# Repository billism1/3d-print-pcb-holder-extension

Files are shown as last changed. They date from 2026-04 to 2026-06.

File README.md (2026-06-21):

# PCB Holder Extension

Two OpenSCAD-designed solutions for mounting wider/longer PCBs that exceed a standard PCB holder's capacity: a cap-on extension and a full arm replacement.

> **📥 Download & print on MakerWorld:** [PCB Holder Arm Extension & Replacement](https://makerworld.com/en/models/2961782-pcb-holder-arm-extension-replacement)

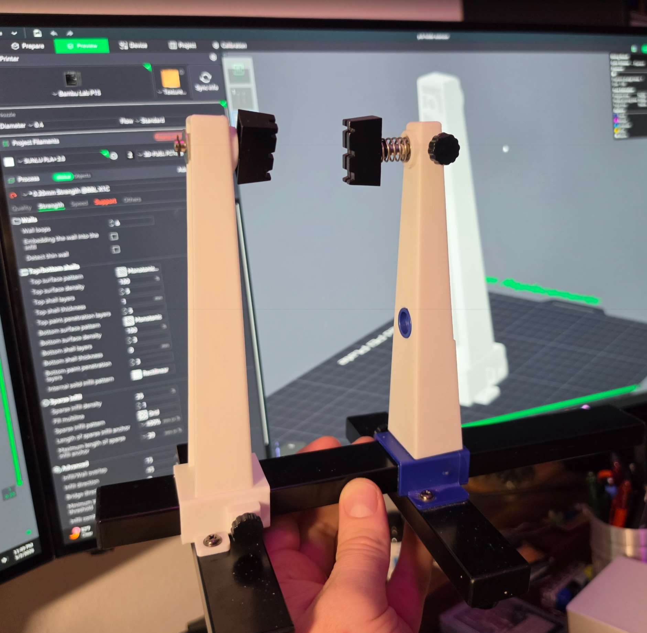
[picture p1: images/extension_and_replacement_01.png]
Extension (right) and full replacement arm (left) on shared base rail


## Target Holders

This extension is designed for standard PCB holders with ~200×140mm max capacity:

| Brand | Model | Max PCB Size | Link |
|---|---|---|---|
| Noah | NH-11E | 200×140mm | [Amazon](https://www.amazon.com/Noah-Adjustable-Soldering-Desoldering-Rotation/dp/B0CY4DRHWK/) |
| Pro's Kit | SN-390 | 200×140mm | [Adafruit](https://www.adafruit.com/product/3791) |

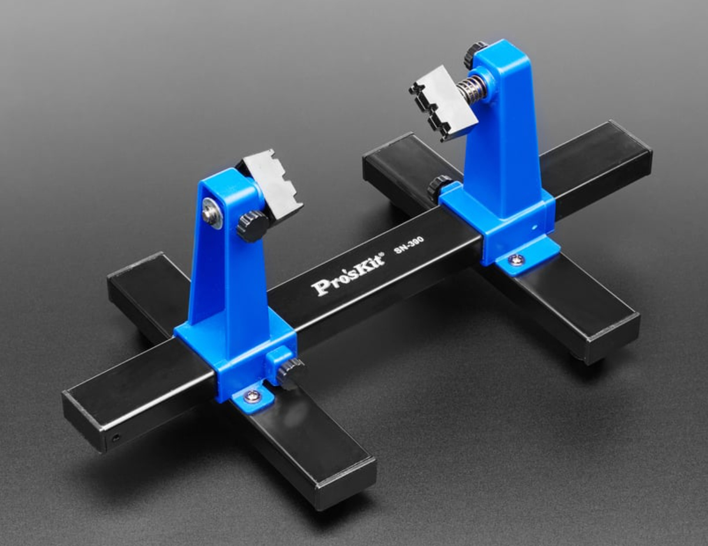
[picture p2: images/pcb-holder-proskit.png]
PCB Holder


### Pro's Kit SN-390 Specifications
- **Material**: ABS arms + metal base
- **Dimensions**: 300 × 165 × 125mm
- **Weight**: 450g
- **Features**: 4 slots for varying PCB thicknesses, non-slip rubber pads, 360° rotation

## Why

Standard PCB holders adjust horizontally and rotate PCBs in spring-loaded braces. Oversized PCBs can't rotate, though — they hit the holder frame. These parts add arm height so larger boards clear it.

Two approaches; choose one:

- **`pcb-holder-extension:`** Caps onto the top of each existing vertical arm, adding height above the original. One piece per side.
- **`pcb-holder-long-arm:`** Full replacement for the vertical arm. Taller profile, no base modification.

Either way, reuse the original holder's hardware.

## Hardware Assembly (Applies to Both Methods)

Both the extension and long arm replacement reuse the original holder's hardware. Follow these steps for either mounting method:

1. Slide the PCB grip bolt (reused from the original holder) through the bolt hole from inside to outside.
2. Place the washer (from the original holder) onto the bolt on the outside.
3. Press the retainer clip (from the original holder) onto the washer to lock it in place. The washer keeps the PCB grip bolt from sliding out, while the grip on the inner side prevents it from going anywhere.

### Mounting Method: Extension

Mounts on **both sides** of the holder (one piece per arm):

1. Slide the extension cap over the top of the existing vertical arm.
2. Follow the hardware assembly steps above.

### Mounting Method: Long Arm (Replacement)

Slides onto the base rail from **either side** as a drop-in replacement:

1. Slide the original vertical arm off the base rail.
2. Remove the hand screw.
3. Slide the replacement arm onto the rail from either side.
4. Reuse the original hand screw and hardware to secure.
5. Follow the hardware assembly steps above.

**Locking the arm in place:** The long arm uses a **rail-lock pin** to lock its position on the rail. This pin presses against the rail from the side, securing the arm without relying on the hand screw alone.

> **Rail-lock pin:** A replacement pin ([`rail-lock-pin.scad`](src/rail-lock-pin.scad) / `rail-lock-pin.stl`) is included in this repo in case the original pin is lost or worn out. The pin sits between the hand-tightened screw and the rail; when the screw is tightened, it presses the pin against the rail to lock the arm's position. When installing the replacement pin using the existing hardware, carefully position the pin in place before securing the hand-tightened screw.

### Measured Arm Dimensions

| View | Bottom | Top |
|---|---|-----|
| Side (force direction) | 30mm | 20mm |
| Front (facing PCB) | 24mm | 16mm |

- **Retainer bolt hole**: 4mm diameter, protrudes ~4mm toward center

## Repository Layout

### Source ([`src/`](src/)) — parametric OpenSCAD

Edit the variables at the top of each file to match your holder, then export your own STL.

- [`src/pcb-holder-extension.scad`](src/pcb-holder-extension.scad) — cap-on extension.
- [`src/pcb-holder-long-arm.scad`](src/pcb-holder-long-arm.scad) — full arm replacement.
- [`src/rail-lock-pin.scad`](src/rail-lock-pin.scad) — replacement rail-lock pin for the long arm.

### Ready-to-print files ([`publication/`](publication/))

Download these directly if the defaults fit a standard ~200×140mm holder (Noah NH-11E / Pro's Kit SN-390):

| File | What it is |
|---|---|
| [`pcb-holder-extension.stl`](publication/pcb-holder-extension.stl) | Cap-on extension. Print **two** (one per arm). |
| [`pcb-holder-long-arm_140mm.stl`](publication/pcb-holder-long-arm_140mm.stl) | Full replacement arm, 140 mm tall. Print **two**. |
| [`pcb-holder-long-arm_164mm.stl`](publication/pcb-holder-long-arm_164mm.stl) | Full replacement arm, taller 164 mm variant for more reach. Print **two**. |
| [`rail-lock-pin.stl`](publication/rail-lock-pin.stl) | Replacement rail-lock pin for the long arm. Print only if the original pin is lost or worn. |
| [`pcb-holder-extension.3mf`](publication/pcb-holder-extension.3mf) | Pre-arranged 3MF project of the extension (open in your slicer). |

## Customization Parameters

### Shared (both files)

Set these to match your physical PCB holder hardware. Both [`src/pcb-holder-extension.scad`](src/pcb-holder-extension.scad) and [`src/pcb-holder-long-arm.scad`](src/pcb-holder-long-arm.scad) have these parameters:

| Parameter | Default | Description |
|---|---|---|
| `retainer_bolt_hole_d` | 5 mm | Diameter of the retainer bolt hole |
| `retainer_boss_od` | 16.5 mm | OD of the boss around the bolt hole on the arm's inner face |
| `retainer_boss_protrude` | 3.5 mm | How far the boss protrudes toward the PCB |
| `hand_screw_thread_d` | 3.85–4 mm | Hand-screw thread OD (M4-ish; 3.85 in extension, 4 in long arm) |
| `hand_screw_nut_af` | 7 mm | Hex nut across-flats (M4) |
| `wall_thickness` | 3 mm | Wall thickness throughout |
| `wall_x_trim` | 3.5 mm | Body width reduction on the open (+X) side |
| `top_bolt_offset_from_top` | 12 mm | Top bolt hole center, measured down from the top of the piece |
| `bolt_clearance` | 0.35 mm | Oversize on bolt through-holes |

### Extension-specific ([`pcb-holder-extension.scad`](src/pcb-holder-extension.scad))

Arm dimensions are measured from your original holder arm. Cap geometry controls the added height.

| Parameter | Default | Description |
|---|---|---|
| `arm_x_bottom` / `arm_x_top` | 23.5 / 16 mm | Arm width in X at bottom / top (front view, retainer-bolt axis) |
| `arm_y_bottom` / `arm_y_top` | 30 / 20 mm | Arm depth in Y at bottom / top (side view, hand-screw axis) |
| `arm_height` | 80 mm | Total height of the original vertical arm |
| `retainer_bolt_z_from_bottom` | 65 mm | Bolt-hole center, measured from the arm bottom |
| `extension_height` | 80 mm | Extra height added above the original arm top |
| `sleeve_depth` | 84 mm | How far the sleeve covers the arm from the top |
| `surface_tolerance` | 0.0 mm | Per-side clearance between sleeve cavity and arm |
| `boss_recess_clearance` | −0.45 mm | Clearance on the boss recess (negative = interference; tune for snug fit) |

### Long arm-specific ([`pcb-holder-long-arm.scad`](src/pcb-holder-long-arm.scad))

Body cross-section and rail parameters for the replacement arm.

| Parameter | Default | Description |
|---|---|---|
| `body_x_bottom` / `body_x_top` | 29.9 / 18.5 mm | Outer body X width at bottom / top |
| `body_y_bottom` / `body_y_top` | 31.3 / 20 mm | Outer body Y depth at bottom / top |
| `body_height` | 164 mm | Total height of the tapered body (rail base up to top cap) |
| `rail_y` / `rail_z` | 30 / 15 mm | Rail cross-section dimensions |
| `rail_clearance` | 0.2 mm | Per-side slip-fit clearance around the rail |
| `rail_base_x` | 40 mm | Rail base grip length along the rail |

## Design Specifications

- **Material**: PLA+, PCTG, PETG, ABS, ASA, or similar (tested with PLA+ and PCTG. Both showed no signs of weakness and either should be plenty strong for most users)
- **Layer height**: 0.2 mm
- **Infill**: 20-25%
- **Supports**: May be required depending on orientation
- **Nozzle**: 0.4 mm (minimum wall: 0.8-1.2 mm)

## Key Features

- **Extension:** caps onto existing arms on both sides; no disassembly required
- **Long arm:** full arm replacement; slides onto the base rail from either side
- Both maintain compatibility with the spring-loaded brace mechanism
- Parametric OpenSCAD design; adjust dimensions to match your holder
- FDM-optimized with proper tolerances

## Suggested Workflow

1. Customize dimensions in OpenSCAD for your specific holder.
2. Export to STL for your slicer.
3. Print with appropriate settings for your material.
4. Mount: slide extension caps onto both arms, or swap in the long arm replacement on each side.
5. Test fit with your largest PCB before rotation.

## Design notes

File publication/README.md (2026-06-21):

# Publication Files

Ready-to-print exports of the designs in [`../src/`](../src/). Tuned for standard ~200×140mm holders (Noah NH-11E / Pro's Kit SN-390).

| File | What it is |
|---|---|
| `pcb-holder-extension.stl` | Cap-on extension. Print two (one per arm). |
| `pcb-holder-long-arm_140mm.stl` | Full replacement arm, 140 mm tall. Print two. |
| `pcb-holder-long-arm_164mm.stl` | Full replacement arm, taller 164 mm variant. Print two. |
| `rail-lock-pin.stl` | Replacement rail-lock pin for the long arm. Print only if the original is lost or worn. |
| `pcb-holder-extension.3mf` | Pre-arranged 3MF project of the extension; open in your slicer. |

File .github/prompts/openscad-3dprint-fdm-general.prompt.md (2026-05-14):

# OpenSCAD – General FDM 3D Printing Prompt

> Use this prompt for any OpenSCAD work targeting FDM (Fused Deposition Modelling) printers.

## Language Rules

OpenSCAD is a **functional CSG modelling language**, not a general-purpose programming language. Follow these rules exactly:

- **Do NOT use mutable variables** — compute all values at parse time
- **Do NOT use `for()` as control flow** — use it as a geometric generator only
- **Do NOT write functions that return values** — modules produce geometry, not data
- **Use `hull()` for fillets and smooth transitions**, not manual chamfer math
- **Use `let()` for named intermediate values** inside expressions
- **Use `each` to flatten nested lists** in list comprehensions
- **Use `children()`** when a module must operate on geometry passed to it
- **`difference()`, `union()`, `intersection()`** are the core boolean CSG operations — prefer these over complex nested geometry
- **`translate()`, `rotate()`, `scale()`** are transforms — always applied to children, never standalone
- **`$fn` controls curve smoothness** — always set it explicitly; never rely on the default

## FDM Design Principles

### Orientation matters
- The **flat, largest face should sit on the build plate** whenever possible.
- Minimise the need for support material by avoiding large unsupported overhangs.
- Vertical cylindrical holes print well; horizontal ones may need tear-drop or bridging profiles.

### Strength considerations
- **Layer lines are weakest in tension along Z.** Design load-bearing features so forces act across (XY) rather than between layers.
- Add fillets at the base of vertical features to distribute stress and reduce stress-risers.
- Prefer rounded transitions over sharp internal corners to avoid stress concentration.

### Printability guidelines
- Avoid very thin walls (< 2 × nozzle diameter). Typical minimum wall thickness: **0.8–1.2 mm** for a 0.4 mm nozzle.
- Bridging spans should stay under **~50 mm** without support.
- Overhangs up to **~45°** from vertical generally print without support; steeper angles may need chamfers or supports.
- Design snap-fits and living hinges with grain direction (layer orientation) in mind.

## OpenSCAD Cheatsheet

https://openscad.org/cheatsheet/

## Common Patterns

### Rounded rectangle (cube with round XY edges)
```openscad
module rounded_rect(size, r) {
    hull() {
        for (x = [r, size.x - r], y = [r, size.y - r])
            translate([x, y, 0])
                cylinder(r = r, h = size.z);
    }
}
```

### Fillet at base of a vertical feature
```openscad
module base_fillet(r, h) {
    difference() {
        cube([r, r, h]);
        translate([r, r, -0.01])
            cylinder(r = r, h = h + 0.02);
    }
}
```

### Chamfered hole (countersink / printer-friendly top)
```openscad
module chamfered_hole(d, h, chamfer = 0.6) {
    union() {
        cylinder(d = d, h = h);
        translate([0, 0, h - chamfer])
            cylinder(d1 = d, d2 = d + 2 * chamfer, h = chamfer + 0.01);
    }
}
```

### Shell / hollow box
```openscad
module shell(outer, wall) {
    difference() {
        cube(outer);
        translate([wall, wall, wall])
            cube([outer.x - 2*wall, outer.y - 2*wall, outer.z]);
    }
}
```

### Slot (elongated hole)
```openscad
module slot(length, d, h) {
    hull() {
        cylinder(d = d, h = h);
        translate([length, 0, 0])
            cylinder(d = d, h = h);
    }
}
```

### Counterbore hole
```openscad
module counterbore_hole(d_through, d_head, h_total, h_head) {
    union() {
        cylinder(d = d_through, h = h_total + 0.01);
        translate([0, 0, h_total - h_head])
            cylinder(d = d_head, h = h_head + 0.01);
    }
}
```

### Text / label emboss or deboss
```openscad
// Debossed (engraved) text on top surface
module debossed_label(txt, size, depth, font = "Liberation Sans:style=Bold") {
    translate([0, 0, -depth])
        linear_extrude(depth + 0.01)
            text(txt, size = size, font = font, halign = "center", valign = "center");
}
```

### Circular pattern (polar array)
```openscad
module polar_array(n, r) {
    for (i = [0 : n - 1])
        rotate([0, 0, i * 360 / n])
            translate([r, 0, 0])
                children();
}
```

## Tolerances for FDM 3D Printing

| Fit Type | Tolerance | Example |
|---|---|---|
| Press-fit (tight interference) | +0.1–0.2 mm on ID | `insert_od + 0.15` |
| Snug / sliding fit | +0.2–0.4 mm | `shaft_d + 0.3` |
| Loose / clearance fit | +0.5–1.0 mm | `cable_d + 0.6` |
| Screw through-hole | +0.3–0.5 mm | `M4 → 4.4 mm hole` |
| Self-threading (screw into plastic) | ~85% of nominal | `M4 → 3.4 mm hole` |
| Mating flat surfaces (stacking) | +0.2 mm per axis | offset to prevent binding |
| Lid / cap fit | +0.3–0.5 mm radial clearance | on diameter |

## Recommended `$fn` Values

| Feature | `$fn` | Notes |
|---|---|---|
| Small holes (< 6 mm) | 24–32 | Keeps file size small, holes still round |
| Medium cylinders (6–30 mm) | 48–64 | Good visual smoothness |
| Large curves / decorative | 96–128 | For visible surfaces |
| Hex shapes | 6 | `cylinder(..., $fn=6)` gives a hexagon |
| Quick preview / development | 16–24 | Faster render while iterating |
| Final export | 64–128 | Use higher values for production STL |

## CSG Best Practices

- Always extend cut volumes by **0.01 mm** (epsilon) beyond the surface to avoid z-fighting / coincident faces.
- Keep geometry **manifold** — no zero-thickness walls, no self-intersecting volumes.
- Use `render()` sparingly; it forces CGAL evaluation and slows preview.
- Name modules descriptively (e.g., `mounting_tab()`, `drain_slot()`) and parametrise dimensions at the top of the file.
- Group related constants together and comment units: `wall = 2.5; // mm`.
- Use `assert()` to guard against invalid parameter combinations.

## File Organisation

```
// 1. Constants & parameters
// 2. Derived dimensions
// 3. Helper / utility modules
// 4. Component modules
// 5. Assembly (top-level geometry)
```

Keep the top-level geometry at the **bottom** of the file so that reading top-to-bottom flows from parameters → helpers → final shape.

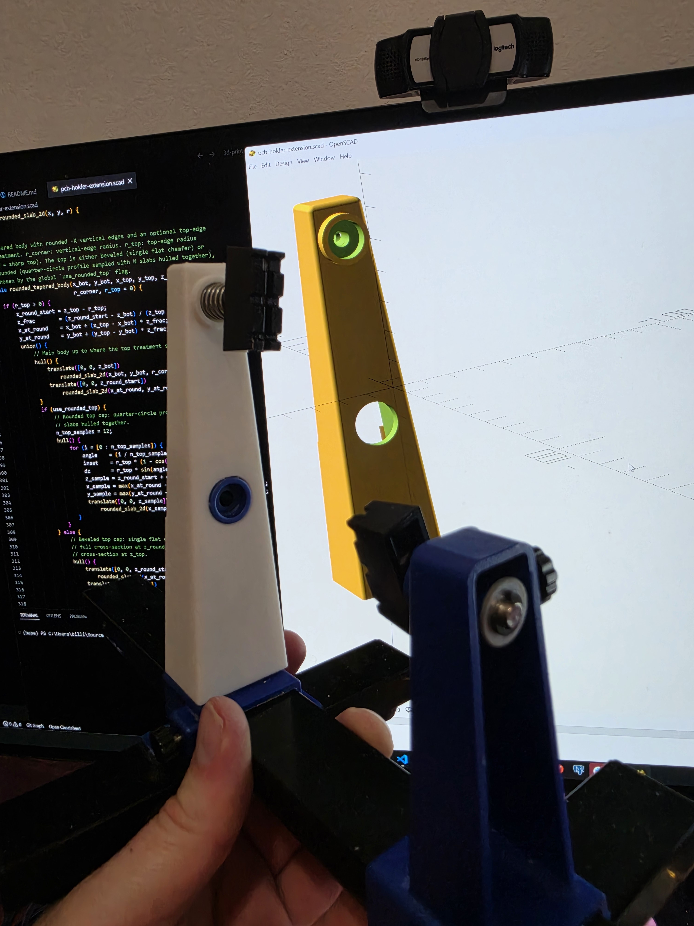
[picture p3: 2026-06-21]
images/snap-on-01.jpg

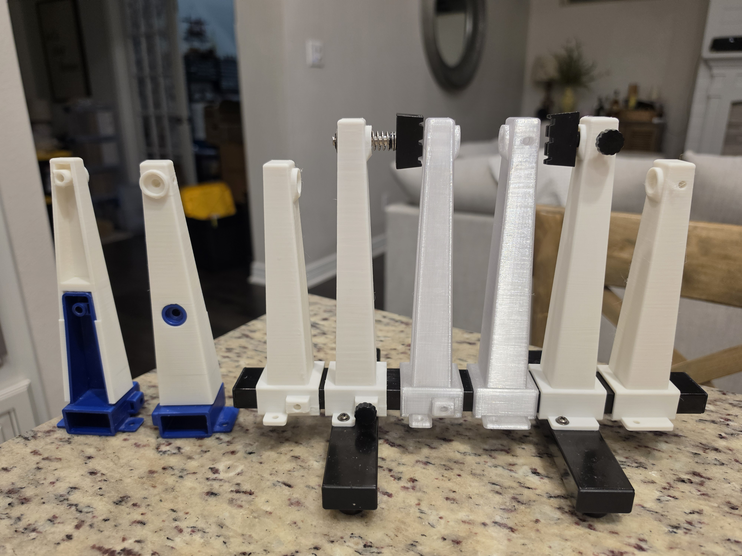
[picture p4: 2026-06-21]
images/all-arms-01.jpg

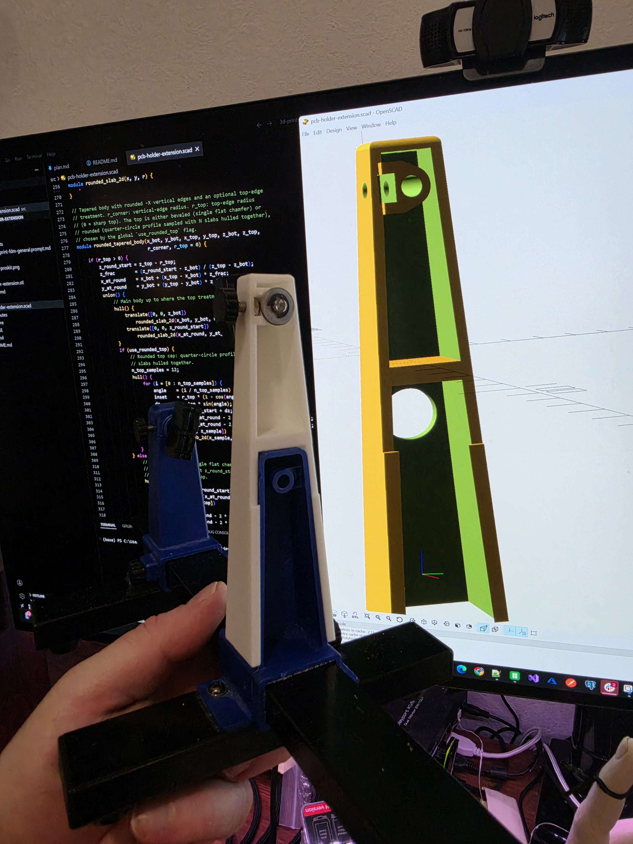
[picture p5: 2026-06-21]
images/snap-on-02.jpg

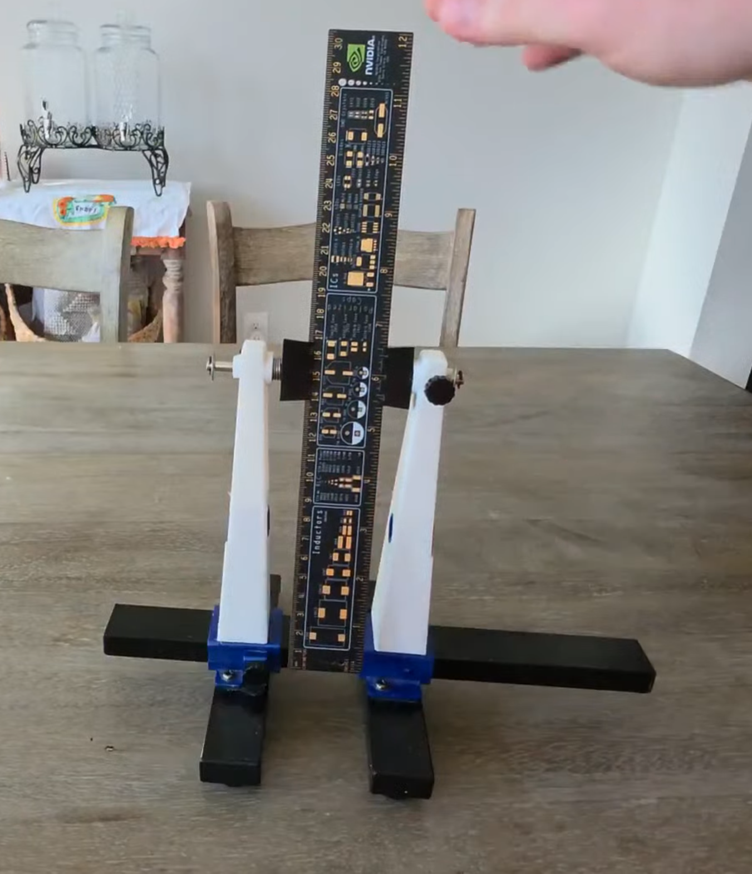
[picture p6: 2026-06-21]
images/arm-extensions-01.png

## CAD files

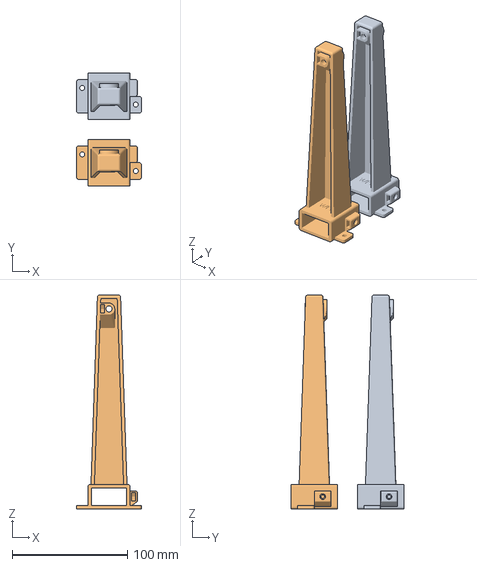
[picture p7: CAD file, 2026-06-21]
publication/pcb-holder-full-replacement.3mf
56.4 x 97.5 x 185.4 mm
pcb-holder-long-arm.stl x 2

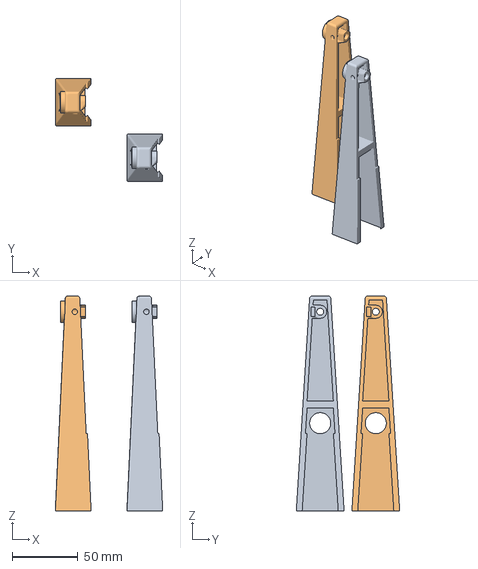
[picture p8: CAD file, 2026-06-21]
publication/pcb-holder-extension.3mf
82.0 x 78.9 x 164.0 mm
pcb-holder-extension.stl x 2

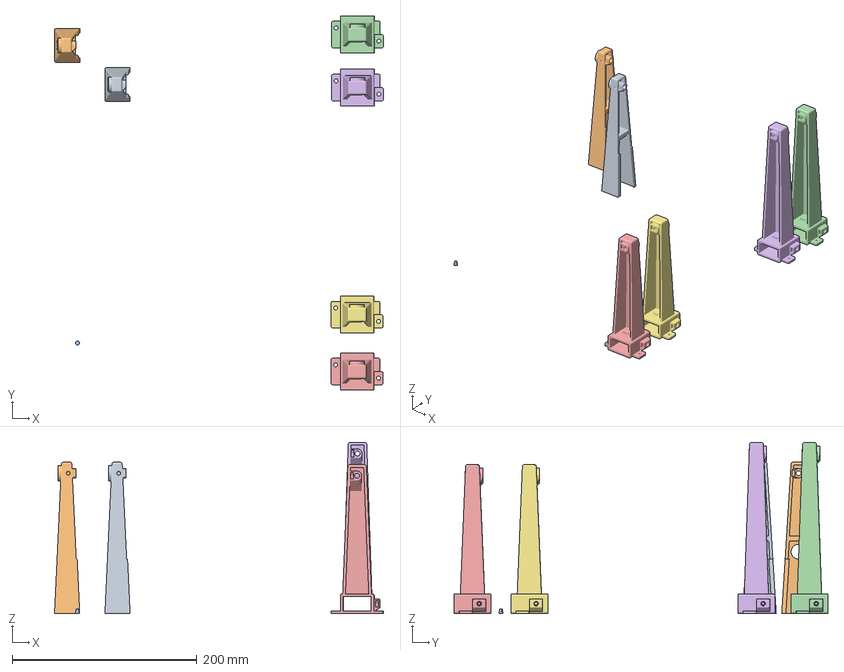
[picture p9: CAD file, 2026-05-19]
publication/pcb-holder-all.3mf
356.6 x 405.3 x 185.4 mm
pcb-holder-extension.stl x 2
rail-lock-pin.stl
pcb-holder-long-arm.stl x 2
pcb-holder-long-arm_140mm.stl x 2

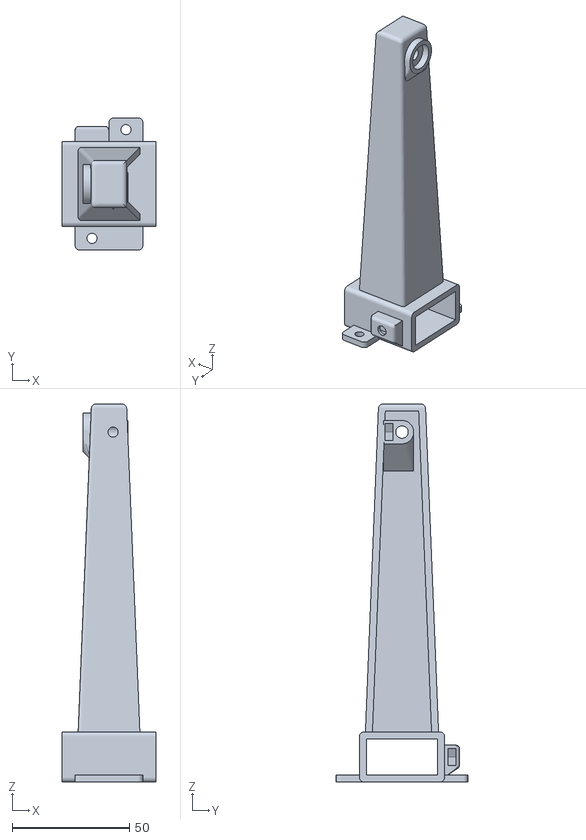
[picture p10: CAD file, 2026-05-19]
publication/pcb-holder-long-arm_140mm.stl
40.0 x 56.4 x 161.4

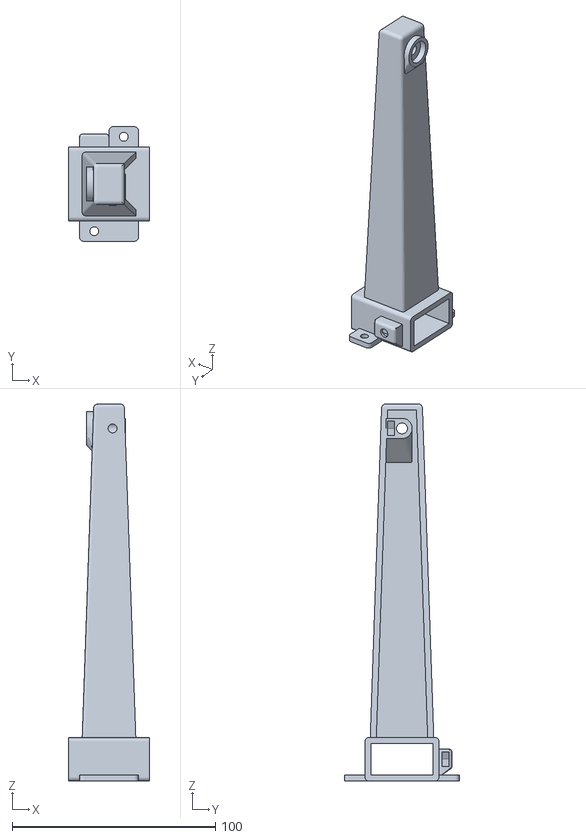
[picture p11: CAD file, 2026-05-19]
publication/pcb-holder-long-arm_164mm.stl
40.0 x 56.4 x 185.4

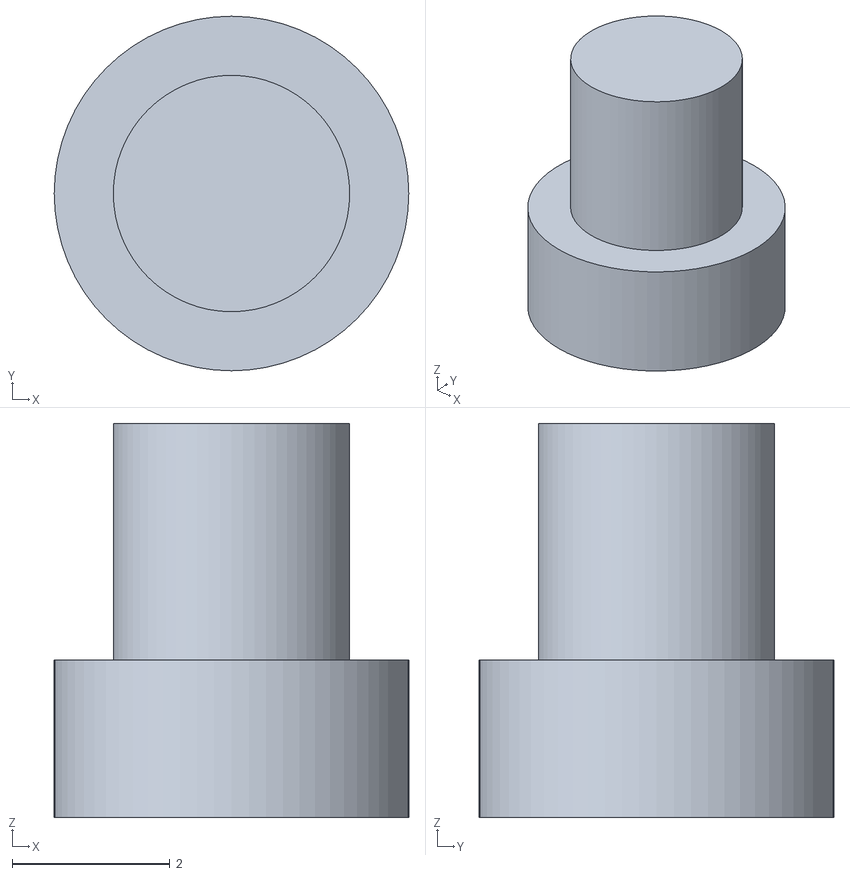
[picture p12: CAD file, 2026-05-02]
publication/rail-lock-pin.stl
4.50 x 4.50 x 5.00

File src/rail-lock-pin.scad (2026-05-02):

//==============================================================================
// Rail-Lock Plastic Pin
//==============================================================================
// Companion piece to the PCB Holder Long Arm. Sits between the rail-locking
// hand-screw and the rail: the screw presses on the pin head, and the pin's
// shaft tip presses on the rail through the rail base outer wall.
//
// Print orientation: head on the build plate, shaft tip pointing up
// (+Z). Dimensions are nominal — the receiving pocket and shaft hole in
// pcb-holder-long-arm.scad already include their own clearance.
//==============================================================================

//==============================================================================
// 1. PIN DIMENSIONS
//==============================================================================

pin_head_d     = 4.5;   // mm - head diameter
pin_head_thick = 2.0;   // mm - head thickness (axial)
pin_shaft_d    = 3;     // mm - shaft diameter
pin_shaft_len  = 3;     // mm - shaft length (tip-to-head)

//==============================================================================
// 2. RENDER QUALITY
//==============================================================================

$fn = 64;
$fa = 0.5;
$fs = 0.1;

//==============================================================================
// 3. GEOMETRY
//==============================================================================

module rail_lock_pin() {
    // Head rests on the build plate (Z = 0 to head thickness),
    // shaft rises from head's top face up to its tip.
    union() {
        // Head
        cylinder(d = pin_head_d, h = pin_head_thick);
        // Shaft, stacked on top of the head
        translate([0, 0, pin_head_thick])
            cylinder(d = pin_shaft_d, h = pin_shaft_len);
    }
}

rail_lock_pin();

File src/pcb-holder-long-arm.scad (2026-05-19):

//==============================================================================
// PCB Holder Long Arm
//==============================================================================
// Target: Standard PCB holders with ~200x140mm max PCB capacity
// Compatible with:
//   - Noah NH-11E (Amazon B0CY4DRHWK)
//   - Pro's Kit SN-390 (Adafruit 3791)
//
// Function: Full replacement for the holder's stock arm. A rail base at the
//           bottom slides over the holder's fixed rectangular rail; the body
//           rises above the rail to a top boss + nut pocket that mate with
//           the original spring-loaded PCB bracket and hand screw. Provides
//           extra reach above the rail vs. the stock arm.
//
// Coordinate system (single piece, "right arm" version):
//   +X = outer side  — OPEN side of the body cavity; rail enters/exits in X
//   -X = inner side  — closed wall; faces PCB center; carries top boss
//   +Y = front       — closed wall; carries hand-screw through-hole
//   -Y = back        — closed wall; carries hand-screw nut pocket
//   +Z = up          — internally, Z = 0 sits at the bottom of the tapered
//                      body, where it meets the top of the rail base. The
//                      final long_arm() output is lifted so the bottom of
//                      the rail base rests on the Z = 0 plane (ready to
//                      drop straight onto a printer bed).
//==============================================================================

//==============================================================================
// 1. INTERFACING HARDWARE (must match the existing PCB bracket)
//==============================================================================

render_mirrored_piece = false;

// Retainer bolt: axis runs along X. Hole passes through the upper part of
// the body and through the inside cylindrical boss on the cavity side.
retainer_bolt_hole_d        = 5;     // mm
retainer_boss_od            = 16.5;  // mm - boss OD on the inner (-X) side face
retainer_boss_protrude      = 3.5;   // mm - how far the boss sticks in -X direction

// Hand screw (locks the retainer bolt; threads in from the -Y back face)
hand_screw_thread_d  = 4;  // mm - measured at thread crests
hand_screw_nut_af    = 7;     // mm - hex nut, across-flats (M4)
hand_screw_nut_thick = 3.0;   // mm - M4 hex nut typical axial thickness

//==============================================================================
// 2. BODY DIMENSIONS
//==============================================================================

// The body is a single tapered tube running from the rail base at the
// bottom (Z = 0) up to a closed top cap (Z = body_height). The
// cross-section tapers linearly across the full height.

// Body OUTER cross-section at the BOTTOM (Z = 0)
body_x_bottom = 29.875;   // mm - X width  (left-right, retainer bolt axis)
body_y_bottom = 31.25;    // mm - Y depth  (front-to-back, hand screw axis)

// Body OUTER cross-section at the TOP (Z = body_height)
body_x_top    = 18.5;     // mm
body_y_top    = 20;     // mm

// Total body height: tapered tube from the rail base up to the top cap
body_height = 164;   // mm

wall_thickness = 3;  // mm

// Trim on the open (+X) side of the body. Shrinks the outer body width by
// this amount on +X only so the -X wall position is preserved and the +X
// face moves inward.
wall_x_trim = 3.5;   // mm

// Upper bolt hole position, measured down from the top of the body
top_bolt_offset_from_top = 12;

// Inside boss: cylindrical sleeve on the cavity side of the -X wall around
// the upper bolt hole. Reinforces the bolt mount with material around the
// 4 mm hole.
inside_boss_od     = 10;    // mm - OD (3 mm wall around 4 mm bolt hole)
inside_boss_length = 13;    // mm - extent into cavity in +X direction

// Nut holder block: rectangular block adjacent to the inside cyl boss on
// the -Y side. Provides material for the hand-screw nut nook with floor +
// ceiling capture. Overlaps the cylindrical boss so they merge into one
// solid mass.
nut_holder_wall_thickness = 1.5;
nut_holder_x      = inside_boss_length;                                 // mm - X depth into cavity from -X cavity face
nut_holder_y_to   = -6;                                                     // mm - +Y extent (block runs from -Y inner wall to here)
nut_holder_z      = (nut_holder_wall_thickness * 2) + hand_screw_nut_af;    // mm - vertical height (centered on upper_bolt_z)

// Hand-screw nut nook (rectangular slot inside the nut holder block).
// Opens on +X so the nut is loaded through the open outer face during
// assembly. Floor and ceiling within the block capture the nut vertically;
// the slot's -Y wall backs up the nut when the screw is tightened.
nut_nook_x_clear  = 0.5;    // mm - radial clearance past hex AV
nut_nook_y_clear  = 0.2;    // mm - axial clearance past nut thickness
nut_nook_z_clear  = 0.1;    // mm - vertical clearance past hex AF
nut_nook_y_center = -5.5;   // mm - Y of nut center along hand-screw path

// Hand-screw blind hole: enters from -Y, ends just past the bolt axis.
// Does NOT punch through the +Y wall.
hand_screw_blind_overshoot = 0.5;   // mm past bolt axis (into inside boss material)

// External top boss is hollowed into a stubby tube so the PCB bracket's
// round peg can insert into it. Wall thickness is the radial material left
// between the inlet (ID) and the boss OD.
top_boss_wall = 2.1;   // mm - radial wall of the boss tube

// Rounded edges (matches the look of the original arm in the photo):
// - edge_corner_radius rounds the two -X (PCB-facing) vertical edges, the
//   ones running the full body height.
// - top_corner_radius adds a chamfer at the very top of the upper body.
// edge_corner_radius must stay smaller than wall_thickness * sqrt(2)/(1+sqrt(2))
// (~1.76 mm at wall_thickness = 3 mm) or the rounded corner cuts past the
// inner cavity wall.
edge_corner_radius = 1.5;   // mm
top_corner_radius  = 2;     // mm

// Top-edge style:
//   false = beveled (single flat chamfer slab — original look)
//   true  = rounded (quarter-circle profile, smooth dome)
// Default: beveled.
use_rounded_top = true;

// Arm label: two-line text engraved into the top of the rail base, inside the
// body cavity. Readable when looking straight down (-Z view). Set either line
// to "" to render only the other (or both "" to disable entirely).
render_arm_label     = true;   // master switch — false skips the engrave entirely
arm_label_line_1     = "WFK";
arm_label_line_2     = "";
arm_label_size       = 5.5;      // mm - character height
arm_label_line_spacing = arm_label_size * 1.3;  // mm - center-to-center between lines
arm_label_depth      = 0.6;    // mm - engrave depth into the rail base top
arm_label_x_center   = 4;   // mm - X center of text block on rail base top
arm_label_y_center   = 0;      // mm - Y center of text block on rail base top
arm_label_angle      = 90;     // deg - in-plane rotation (0 = along +X, 90 = along +Y)
arm_label_mirror     = false;  // flip text horizontally if it reads backwards
//arm_label_font       = "Goudy Stout:style=Bold";  // OpenSCAD font spec ("Family:style=Style")
//arm_label_font       = "Mistral:style=Bold";  // OpenSCAD font spec ("Family:style=Style")
//arm_label_font       = "Winter Wishes:style=Bold";  // OpenSCAD font spec ("Family:style=Style")
//arm_label_font       = "Forte:style=Bold";  // OpenSCAD font spec ("Family:style=Style")
arm_label_font       = "Comic Sans MS:style=Bold";  // OpenSCAD font spec ("Family:style=Style")

// Per-line text alignment. halign: "left" | "center" | "right".
// valign: "top" | "center" | "baseline" | "bottom". Each line is positioned
// independently relative to its own line center; useful for stacking lines of
// different lengths neatly (e.g., both "left" so they share a left edge).
arm_label_line_1_halign = "center";
arm_label_line_1_valign = "center";
arm_label_line_2_halign = "center";
arm_label_line_2_valign = "center";

// Rail base: rectangular box at the bottom of the body with a through-hole
// along the X axis. The fixed rail slides through the hole; the entire arm
// translates along the rail in X. The rail runs parallel to the retainer
// bolt axis. Wall thickness around the rail matches `wall_thickness`.
rail_y         = 30;     // mm - rail cross-section width  (Y axis)
rail_z         = 15;     // mm - rail cross-section height (Z axis)
rail_clearance = 0.2;    // mm - per-side slip-fit clearance around the rail
rail_base_x    = 40;     // mm - X length of the rail base (grip along the rail)
rail_base_corner_r = 2;  // mm - radius on the 4 outer corners (viewed along X)
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

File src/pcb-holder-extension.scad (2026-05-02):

//==============================================================================
// PCB Holder Extension
//==============================================================================
// Target: Standard PCB holders with ~200x140mm max PCB capacity
// Compatible with:
//   - Noah NH-11E (Amazon B0CY4DRHWK)
//   - Pro's Kit SN-390 (Adafruit 3791)
//
// Function: C-shaped channel that slips onto the arm horizontally from the
//           inner side (toward PCB center). The arm's protruding retainer
//           boss enters through the open outer face. Secured through the
//           original retainer-bolt hole. Extends the arm upward and provides
//           an identical boss + nut pocket at its top so the original
//           spring-loaded PCB bracket and hand screw remount on the extension.
//
// Coordinate system (single piece, "right arm" version):
//   +X = outer side  — OPEN; this is the side the extension slips on from
//   -X = inner side  — closed wall; faces PCB center; carries top boss
//   +Y = front       — closed wall; carries hand-screw through-hole
//   -Y = back        — closed wall; carries hand-screw nut pocket
//   +Z = up          — origin Z = 0 sits at the top face of the arm
//==============================================================================

//==============================================================================
// 1. TARGET HOLDER DIMENSIONS (measured)
//==============================================================================

render_mirrored_piece = false;

// Arm cross-section (tapers linearly bottom -> top over arm_height)
arm_x_bottom = 23.5;   // mm - "front view" width  (left-right, retainer bolt axis)
arm_x_top    = 16;
arm_y_bottom = 30;   // mm - "side view" width   (front-to-back, hand screw axis)
arm_y_top    = 20;
arm_height   = 80;   // mm

// Retainer-bolt hole on the arm
retainer_bolt_hole_d        = 5;     // mm
retainer_bolt_z_from_bottom = 65;    // mm - center of hole, from arm bottom
retainer_boss_od            = 16.5;  // mm - boss OD on the inner side face
retainer_boss_protrude      = 3.5;     // mm - how far the boss sticks toward center

// Hand screw (locks the retainer bolt; threads in from front-or-back face)
hand_screw_thread_d  = 3.85;  // mm - measured at thread crests
hand_screw_nut_af    = 7;     // mm - hex nut, across-flats (M4)
hand_screw_nut_thick = 3.0;   // mm - M4 hex nut typical axial thickness

//==============================================================================
// 2. EXTENSION PARAMETERS
//==============================================================================

extension_height = 80;   // mm - rise above arm top (parameter; tune as needed)
sleeve_depth     = 84;   // mm - how far the sleeve covers the arm from the top
wall_thickness   = 3;    // mm

// Vertical thickness of the sleeve ceiling. Defaults to wall_thickness so
// the ceiling matches the side walls. Increase to lower the ceiling: the
// arm seats deeper into the sleeve, and the lower bolt hole position
// follows automatically (see derived `lower_bolt_z`).
// Example: set to wall_thickness + 2 to lower the ceiling by 2 mm.
sleeve_ceiling_thickness = wall_thickness;   // mm

// Optional manual Z offset for the lower bolt hole, on top of the auto
// position derived from where the arm seats. Positive moves the hole up
// (less negative Z), negative moves it down. Use to fine-tune alignment
// with the actual arm if measurements drift.
lower_bolt_z_tweak = 3.5;   // mm

raise_base_ext_sep_wall = 2.5;

// Trim length of the side walls (+Y, -Y) and the closed -X wall along the
// X axis. Shrinks the outer body width by this amount on the open (+X) side
// only so the -X wall position is preserved and the +X face moves inward.
wall_x_trim      = 3.5;    // mm

// Mirrors original arm: top mounting hole this far below extension top
top_bolt_offset_from_top = 12;

// Boss clearance: hole on the -X wall at lower_bolt_z that lets the arm's
// 15.8 mm boss seat fully through the wall. With wall_thickness < boss
// protrusion, this hole punches all the way through the -X wall.
boss_recess_clearance = -0.45;   // mm - added to OD for slip fit over boss

// Inside boss: cylindrical sleeve on the cavity side of the -X wall around
// the upper bolt hole. Mimics the round wall on the original arm interior —
// reinforces the bolt mount with 3 mm of wall material around the 4 mm hole.
inside_boss_od     = 10;    // mm - OD (3 mm wall around 4 mm bolt hole)
inside_boss_length = 13;     // mm - extent into cavity in +X direction

// Nut holder block: rectangular block adjacent to the inside cyl boss on
// the -Y side. Provides material for the hand-screw nut nook with floor +
// ceiling capture. Overlaps the cylindrical boss so they merge into one
// solid mass.
nut_holder_wall_thickness = 1.5;
nut_holder_x      = inside_boss_length - 4;                                 // mm - X depth into cavity from -X cavity face
nut_holder_y_to   = -6;                                                     // mm - +Y extent (block runs from -Y inner wall to here)
nut_holder_z      = (nut_holder_wall_thickness * 2) + hand_screw_nut_af;    // mm - vertical height (centered on upper_bolt_z)

// Hand-screw nut nook (rectangular slot inside the nut holder block).
// Opens on +X so the nut is loaded through the open outer face during
// assembly. Floor and ceiling within the block capture the nut vertically;
// the slot's -Y wall backs up the nut when the screw is tightened.
nut_nook_x_clear  = 0.5;    // mm - radial clearance past hex AV
nut_nook_y_clear  = 0.2;    // mm - axial clearance past nut thickness
nut_nook_z_clear  = 0.1;    // mm - vertical clearance past hex AF
nut_nook_y_center = -5.5;   // mm - Y of nut center along hand-screw path

// Hand-screw blind hole: enters from -Y, ends just past the bolt axis.
// Does NOT punch through the +Y wall.
hand_screw_blind_overshoot = 0.5;   // mm past bolt axis (into inside boss material)

// External top boss is hollowed into a stubby tube so the PCB bracket's
// round peg can insert into it. Wall thickness is the radial material left
// between the inlet (ID) and the boss OD.
top_boss_wall = 2.1;   // mm - radial wall of the boss tube

// Rounded edges (matches the look of the original arm in the photo):
// - edge_corner_radius rounds the two -X (PCB-facing) vertical edges, the
//   ones running the full sleeve+upper-body height.
// - top_corner_radius adds a chamfer at the very top of the upper body.
// edge_corner_radius must stay smaller than wall_thickness * sqrt(2)/(1+sqrt(2))
// (~1.76 mm at wall_thickness = 3 mm) or the rounded corner cuts past the
// inner cavity wall.
edge_corner_radius = 1.5;   // mm
top_corner_radius  = 2;     // mm

// Top-edge style:
//   false = beveled (single flat chamfer slab — original look)
//   true  = rounded (quarter-circle profile, smooth dome)
// Default: beveled.
use_rounded_top = false;

// Snap-fit lips on the cavity side of the +Y/-Y walls, lower portion of the
// sleeve only. Wedge-shaped: flush with the cavity face at the -X end of
// the wedge, protruding into the cavity by snap_fit_lip at the +X end (the
// open mouth). The +Y/-Y walls flex outward as the arm is pushed past the
// wedge, gripping the arm via interference.
snap_fit_lip      = 1.5;    // mm - inward depth at the lip's +X tip
snap_fit_x_length = 1.5;      // mm - X length of the wedge ramp
snap_fit_z_top    = -25;    // mm - top Z of the lip range (extension coords)

// Wall X extension: where the snap-fit grips are, the +Y and -Y walls
// extend further in the +X direction by this amount, making the walls
// "longer" along X in the snap-fit region. The snap-fit lip wedge follows
// to the new leading edge so the lip is at the extended wall's tip.
snap_fit_wall_x_extend = 1;    // mm - extra X length of the walls in the snap-fit region

//==============================================================================
// 3. TOLERANCES
//==============================================================================

surface_tolerance = 0.0;   // mm - per side, sleeve cavity vs arm
bolt_clearance    = 0.35;  // mm - oversize on bolt through-holes
nut_pocket_depth  = 3;     // mm - hex pocket depth
eps               = 0.01;  // mm - epsilon to avoid coincident faces

//==============================================================================
// 4. RENDER QUALITY
//==============================================================================

$fn = 64;
$fa = 0.5;
$fs = 0.1;

//==============================================================================
// 5. DERIVED DIMENSIONS
//==============================================================================

// Linear interpolation of arm width at a given height (z from arm bottom)
function arm_x_at(z) = arm_x_bottom + (arm_x_top - arm_x_bottom) * z / arm_height;
function arm_y_at(z) = arm_y_bottom + (arm_y_top - arm_y_bottom) * z / arm_height;
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

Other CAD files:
publication/pcb-holder-extension.stl

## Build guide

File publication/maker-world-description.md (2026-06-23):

# PCB Holder Arm Extension & Replacement: Hold Oversized PCBs (Noah NH-11E / Pro's Kit SN-390)

Two 3D-printable solutions for holding wider/taller PCBs that a standard PCB holder can't rotate: a cap-on **extension** that adds height to your existing arms, and a full **replacement arm** that swaps onto the base rail. Compatible with common ~200×140mm holders.

> **Disclaimer:** Independent, non-commercial project. **Not affiliated with, authorized, sponsored, or endorsed by Noah, Pro's Kit, or any holder manufacturer.** Brand and model names ("Noah," "NH-11E," "Pro's Kit," "SN-390") are used only to identify the holders these parts are compatible with (nominative fair use). All trademarks are the property of their respective owners.

> **Source & Documentation:** Full OpenSCAD source, photos, and documentation: [github.com/billism1/3d-print-pcb-holder-extension](https://github.com/billism1/3d-print-pcb-holder-extension)

This one's my dad's fault. He designs and works on PCBs bigger than these standard holders can handle. The spring-loaded braces grab the board fine, but it's just too long or wide to flip. So he asked me, very casually, if I could maybe make some kind of little extension for the arms. The fix is conceptually simple: just *more arm*, lifting the grip point higher so a big board clears the frame as it spins.

So I designed the snap-on extension. Done, right? Except then I had the thought every person with a 3D printer, poor impulse control, and a compulsion to over-engineer has had right before losing a weekend: "*...it really wouldn't be much more effort to just...*" And that's how the full arm replacement happened too. Turned out to be maybe 30% more effort, which my brain rounded down to "free". Now there are two solutions instead of one.

Full disclosure: I dabble in electronics, but I rarely touch PCBs big enough to actually need this. This was a Father's Day gift. And I'll be honest: when my dad came over for Father's Day this year (2026) and saw these, I'm fairly sure the parts got a warmer reception than the rest of us did. Which I completely understand and kind of expected, knowing my dad. A custom-fit arm for the exact holder that's been annoying you for months? *That* you don't see coming. No notes, Dad. Priorities respected.

Both designs are built to **reuse all the original hardware from your holder's stock arms**, with nothing proprietary and no extra parts to source. Specifically, they reuse:

- The **PCB grip bolt**
- The **washer**
- The **retainer clip**
- The **hand screw** (and its **M4 hex nut**)

If your holder is one of the common ~200×140mm ones, the included print files should drop right in. If it's something else, the OpenSCAD source is on GitHub and every measurement is a variable at the top of the file.

## Two Approaches (Pick One)

**Approach 1: Cap-On Extension**
A C-shaped sleeve that slips down over the **top of your existing vertical arm** from the inner (PCB-facing) side. It reuses the original retainer bolt hole to lock on, and gives you an identical boss + captive-nut pocket at *its* top so the original spring-loaded PCB bracket and hand screw remount on the extension instead. No disassembly of the holder, no base modification. Print **two** (one per arm).

**Approach 2: Full Replacement Long Arm**
A complete drop-in replacement for the holder's stock vertical arm. A rail base at the bottom slides onto the holder's fixed rectangular rail; the body rises taller than the stock arm to a matching top boss + nut pocket. Includes a **side rail-lock pin** so you can lock the arm's position on the rail independently. Slides on from either side. Print **two**.

Either way, you reuse the holder's original hardware (grip bolt, washer, retainer clip, hand screw).

## What's Included

| File | What it is |
|---|---|
| `pcb-holder-extension.stl` | Cap-on extension. Print **two** (one per arm). |
| `pcb-holder-long-arm_140mm.stl` | Full replacement arm, 140 mm tall. Print **two**. |
| `pcb-holder-long-arm_164mm.stl` | Full replacement arm, taller 164 mm variant for extra reach. Print **two**. |
| `rail-lock-pin.stl` | Replacement rail-lock pin for the long arm. Print only if your original pin is lost or worn. |
| `pcb-holder-extension.3mf` | Pre-arranged 3MF project of the extension. Open straight in your slicer. |

Pick the extension **or** one of the two long-arm heights. The two long-arm files are just different reach amounts, so print whichever clears your board.

## Compatibility

Designed and measured against standard PCB holders with ~200×140mm max capacity:

- **Noah NH-11E** (Amazon B0CY4DRHWK)
- **Pro's Kit SN-390** (Adafruit 3791)

These two appear to share the same arm/rail geometry. If your holder looks like these, the default print files should fit. If you're not sure, measure your arm against the dimensions below before printing two of anything.

**Measured stock arm dimensions:**

| View | Bottom | Top |
|---|---|-----|
| Side (force direction) | 30 mm | 20 mm |
| Front (facing PCB) | 24 mm | 16 mm |

Retainer bolt hole ~4 mm diameter; boss protrudes ~4 mm toward the board.

## Key Features

- **Reuses all original hardware:** grip bolt, washer, retainer clip, and hand screw all carry over. Nothing proprietary.
- **Captive nut pockets:** the hand-screw nut loads into a pocket through the open side and is captured top/bottom, so you're not fishing for a loose nut during assembly.
- **Rounded PCB-facing edges** to match the look of the stock arm.
- **Long arm has a side rail-lock pin** that presses the rail from the side, locking the arm's position without relying on the hand screw alone.
- **Self-supporting geometry:** bosses and internal blocks are tapered so most of it prints without support.
- **Fully parametric OpenSCAD:** every holder dimension is a variable. Different holder? Edit and re-export.

## Print Settings

- **Material:** PLA+, PETG, PCTG, ABS, ASA, or similar. Tested with PLA+ and PCTG; both showed no signs of weakness and either should be plenty strong for most users.
- **Layer height:** 0.2 mm
- **Infill:** 20–25%
- **Walls:** 0.4 mm nozzle, 0.8–1.2 mm minimum wall
- **Supports:** May be needed depending on orientation; the included files are oriented to minimize them.

## Assembly

**Shared hardware steps (both approaches):**
1. Slide the PCB grip bolt (reused from the original holder) through the bolt hole from the inside to the outside.
2. Place the original washer onto the bolt on the outside.
3. Press the original retainer clip onto the washer to lock it. The washer stops the grip bolt from sliding out; the inner grip holds the rest in place.

**Extension:**
1. Slide the extension cap down over the top of the existing vertical arm from the inner side.
2. Secure through the original retainer-bolt hole, then follow the shared hardware steps above.
3. Remount the spring-loaded PCB bracket and hand screw on the extension's top boss.
4. Repeat for the other arm.

**Long Arm (Replacement):**
1. Slide the original vertical arm off the base rail and remove the hand screw.
2. Slide the replacement arm onto the rail from either side.
3. Lock its position with the rail-lock pin and hand screw.
4. Follow the shared hardware steps above to remount the PCB bracket.
5. Repeat for the other arm.

> **Rail-lock pin:** The pin sits between the hand-tightened screw and the rail; tightening the screw presses the pin against the rail to lock the arm's position. A replacement pin STL is included in case the original is lost or worn. Position it carefully before tightening the screw.

## Customizing for a Different Holder

Everything is parametric. If your holder isn't one of the two listed above, grab the OpenSCAD source from GitHub, measure your arm (cross-section at top and bottom, bolt height, rail size), set the variables at the top of the file, and export your own STL.

- `pcb-holder-extension.scad`: cap-on extension
- `pcb-holder-long-arm.scad`: full arm replacement
- `rail-lock-pin.scad`: replacement rail-lock pin

## Notes

Test-fit with your largest PCB *before* you rely on this for a rotation. The whole point is clearing the frame on rotation, so spin it through the full range and make sure nothing collides. Use at your own risk; it's a printed bracket holding a board you presumably care about.

## Source & Documentation

OpenSCAD source, photos, and full documentation: [github.com/billism1/3d-print-pcb-holder-extension](https://github.com/billism1/3d-print-pcb-holder-extension)

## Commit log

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2026-04-26 Removed generated code since it was all wrong.
    [pcb-holder-extension.scad]
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2026-04-26 Enhance upper body module with solid top cap and cavity adjustments
    [pcb-holder-extension.scad]
2026-04-30 Add inside boss and nut nook for hand-screw assembly in upper body module
    [pcb-holder-extension.scad]
2026-04-30 Refactor inside boss and nut nook for improved hand-screw assembly support
    [pcb-holder-extension.scad]
2026-04-30 Adjust nut nook Y center for improved hand-screw alignment
    [pcb-holder-extension.scad]
2026-04-30 Refactor cavity and boss dimensions for improved fit and assembly of hand-screw components
    [pcb-holder-extension.scad, pcb-holder-extension.stl]
2026-04-30 Refactor hand-screw blind overshoot and add top boss inlet for improved PCB bracket compatibility
    [pcb-holder-extension.scad]
2026-04-30 Add settings configuration for OpenSCAD execution and output generation
    [pcb-holder-extension.stl]
2026-04-30 Add wall trimming for improved sleeve and upper body fit
    [pcb-holder-extension.scad]
2026-04-30 Refactor upper body dimensions for seamless sleeve integration and improve cavity design for enhanced structural integrity
    [pcb-holder-extension.scad]
2026-04-30 Adjust retainer-bolt hole diameter and reduce nut nook vertical clearance for improved fit and assembly
    [pcb-holder-extension.scad]
2026-04-30 Refactor top boss positioning and inlet geometry for improved integration with PCB bracket
    [pcb-holder-extension.scad]
2026-04-30 Increase sleeve depth for improved coverage over arm
    [pcb-holder-extension.scad]
2026-04-30 Add sleeve ceiling thickness and lower bolt hole adjustment for improved fit
    [pcb-holder-extension.scad]
2026-04-30 Adjust arm top width and nut nook Y center for improved fit and clearance
    [pcb-holder-extension.scad]
2026-04-30 Adjust arm top height, wall thickness, and bolt offset for improved fit and clearance
    [pcb-holder-extension.scad]
2026-05-01 Adjust retainer boss outer diameter, sleeve depth, and lower bolt hole tweak for improved fit and alignment
    [pcb-holder-extension.scad, pcb-holder-extension.stl]
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2026-05-01 Update PCB holder extension model for improved design
    [pcb-holder-extension.stl]
2026-05-01 Adjust top bolt offset for improved fit and clearance
    [pcb-holder-extension.scad]
2026-05-01 Adjust boss recess clearance for improved fit over the arm's boss
    [pcb-holder-extension.scad]
2026-05-01 Adjust surface tolerance to zero for improved fit in sleeve cavity
    [pcb-holder-extension.scad]
2026-05-01 Adjust wall trim and bolt clearance for improved fit
    [pcb-holder-extension.scad]
2026-05-01 Adjust retainer boss outer diameter and boss recess clearance for improved fit
    [pcb-holder-extension.scad]
2026-05-01 Adjust lower bolt Z position and add base extension separation wall for improved alignment
    [pcb-holder-extension.scad]
2026-05-01 Moving lower bolt Z position down 1 mm after testing print.
    [pcb-holder-extension.scad]
2026-05-01 Adjust lower bolt Z position for improved alignment
    [pcb-holder-extension.scad]
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2026-05-01 Adjust top boss wall thickness for improved fit
    [pcb-holder-extension.scad]
2026-05-01 Increase render quality by adjusting fragment number for smoother output
    [pcb-holder-extension.scad]
2026-05-01 Add rounded edges and chamfer to PCB holder extension for improved aesthetics
    [pcb-holder-extension.scad]
2026-05-01 Adjust top boss wall thickness for improved fit and compatibility
    [pcb-holder-extension.scad]
2026-05-01 Update PCB holder extension model for improved design and compatibility
    [pcb-holder-extension.stl]
2026-05-01 Increase inside boss length for improved fit and clearance
    [pcb-holder-extension.scad]
2026-05-01 Refactor top cap to use rounded edges for improved aesthetics and smooth transitions
    [pcb-holder-extension.stl, pcb-holder-extension_before_rounded_cap.scad]
2026-05-01 Increase extension height and sleeve depth for improved coverage; adjust bolt alignment and render quality settings
    [pcb-holder-extension.scad]
2026-05-01 Increase extension height to 60mm and adjust top boss wall thickness to 2mm for improved stability and fit
    [pcb-holder-extension.scad]
2026-05-01 Increase inside boss length to 13mm for improved fit and clearance
    [pcb-holder-extension.scad]
2026-05-01 Update PCB holder extension model for improved design and functionality
    [pcb-holder-extension.stl]
2026-05-01 Add snap-fit lips to sleeve for improved arm grip and stability
    [pcb-holder-extension.scad]
2026-05-01 Add snap-fit wall extension for improved grip and stability
    [pcb-holder-extension.scad]
2026-05-01 Refine arm cross-section dimensions and increase sleeve depth for improved fit and coverage
    [pcb-holder-extension.scad]
2026-05-02 Increase inward depth of snap-fit lip for improved grip
    [pcb-holder-extension.scad, pcb-holder-extension.stl]
2026-05-02 Blend nut holder into inside boss for smoother transitions
    [pcb-holder-extension.scad]
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2026-05-02 Creating duplicate of the current extension design . Going to develop it into a complete replacement for the stock arm that has the rail slide into it.
    [pcb-holder-long-arm.scad]
2026-05-02 wip for arm replacement.
    [pcb-holder-long-arm.scad]
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2026-05-02 Adjust nut holder dimensions for improved fit and change top profile to beveled
    [pcb-holder-extension.scad]
2026-05-02 Adjust nut nook dimensions for improved fit and clearance
    [pcb-holder-extension.scad]
2026-05-02 Adjust top boss wall thickness and enable rounded top for improved aesthetics
    [pcb-holder-extension.scad, pcb-holder-extension.stl]
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2026-05-02 Refine nut holder dimensions and adjust top boss wall thickness for improved fit and aesthetics
    [pcb-holder-long-arm.scad]
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2026-05-02 Clarify Z-axis origin description and adjust rail base positioning in long arm module
    [pcb-holder-long-arm.scad]
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2026-05-02 Add support for half-width screw plates to improve compatibility with additional components
    [pcb-holder-long-arm.scad]
2026-05-02 Add mounting holes for screw plates to enhance stability and compatibility
    [pcb-holder-long-arm.scad]
2026-05-02 Add side nut holder and locking screw mechanism for enhanced stability
    [pcb-holder-long-arm.scad]
2026-05-02 Refine side nut holder design for self-supporting print face and adjust rail base corner radius
    [pcb-holder-long-arm.scad]
2026-05-02 Adjust rail cross-section dimensions for improved fit and stability
    [pcb-holder-long-arm.scad, pcb-holder-long-arm.stl]
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2026-05-02 Adjust top cross-section dimensions for improved fit and stability
    [pcb-holder-long-arm.scad, pcb-holder-long-arm.stl]
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2026-05-02 Adjust hand screw thread diameter and rail clearance for improved fit
    [pcb-holder-long-arm.scad, pcb-holder-long-arm.stl]
2026-05-02 Adjust rail base corner radius for improved fit and stability
    [pcb-holder-long-arm.scad]
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2026-05-02 Adjust pin head diameter and outer hole calculation for improved assembly fit
    [pcb-holder-long-arm.scad]
2026-05-02 Adjust pin head thickness for improved fit and add rail-lock plastic pin module
    [pcb-holder-long-arm.scad, rail-lock-pin.scad]
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2026-05-02 Add corner radius to side nut holder for improved fit and printability
    [pcb-holder-long-arm.scad, pcb-holder-long-arm.stl]
2026-05-02 Adjust outer hole diameter for side nut holder to enhance assembly fit
    [pcb-holder-long-arm.scad]
2026-05-02 Add self-supporting taper to top boss and inside cluster for improved printability
    [pcb-holder-long-arm.scad]
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2026-05-13 Update README to clarify mounting methods for PCB holder extension and long arm replacement
2026-05-13 Add rail-lock pin instructions and replacement details for long arm in README
2026-05-13 Clarify solutions for mounting wider PCBs in README, detailing cap-on extension and full arm replacement options
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2026-05-13 Correct PCB grip bolt assembly instructions
    The mounting instructions now accurately describe the assembly process:
    - Slide the PCB grip bolt (from original holder) through the hole
    - Place the washer (from original holder) on the bolt
    - Press the retainer clip (from original holder) to lock the washer in place
    This clarifies that all hardware is reused from the original product and corrects the misleading mention of threading/screwing.
2026-05-13 Update README: move hardware assembly instructions to shared section
    The PCB grip bolt, washer, and retainer clip assembly steps apply to both the extension and long arm replacement. Move these instructions to a new "Shared Hardware Assembly" section so users know this applies to both mounting methods.
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2026-05-19 Add new STL files for 140mm and 164mm PCB holder long arms
    [pcb-holder-long-arm.stl, pcb-holder-long-arm_140mm.stl, pcb-holder-long-arm_164mm.stl]
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
